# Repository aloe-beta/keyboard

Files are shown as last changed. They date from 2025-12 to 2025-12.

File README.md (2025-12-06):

# Keyboard

A low-profile split keyboard with 56 hotswappable, RGB backlit keys. Powered by an ESP32-S3.

This is the first project I'm trying to get a PCB manufactured for. I've polished the design up to a point I'm happy with, but there might be mistakes.

The directory structure should be self-explanatory. Currently, `firmare/` only contains a blink program. I'm still deciding whether I should try porting ZMK (ESP32-S3 requires some work) or writing my own firmware from scratch. The latter option would give me more freedom to experiment with the hardware (I have some unconventional ideas), so I'm leaning towards that.

The BOM does not contain anything for the housing or keycaps, as I intend to resin-print those myself.

**Schematic:**

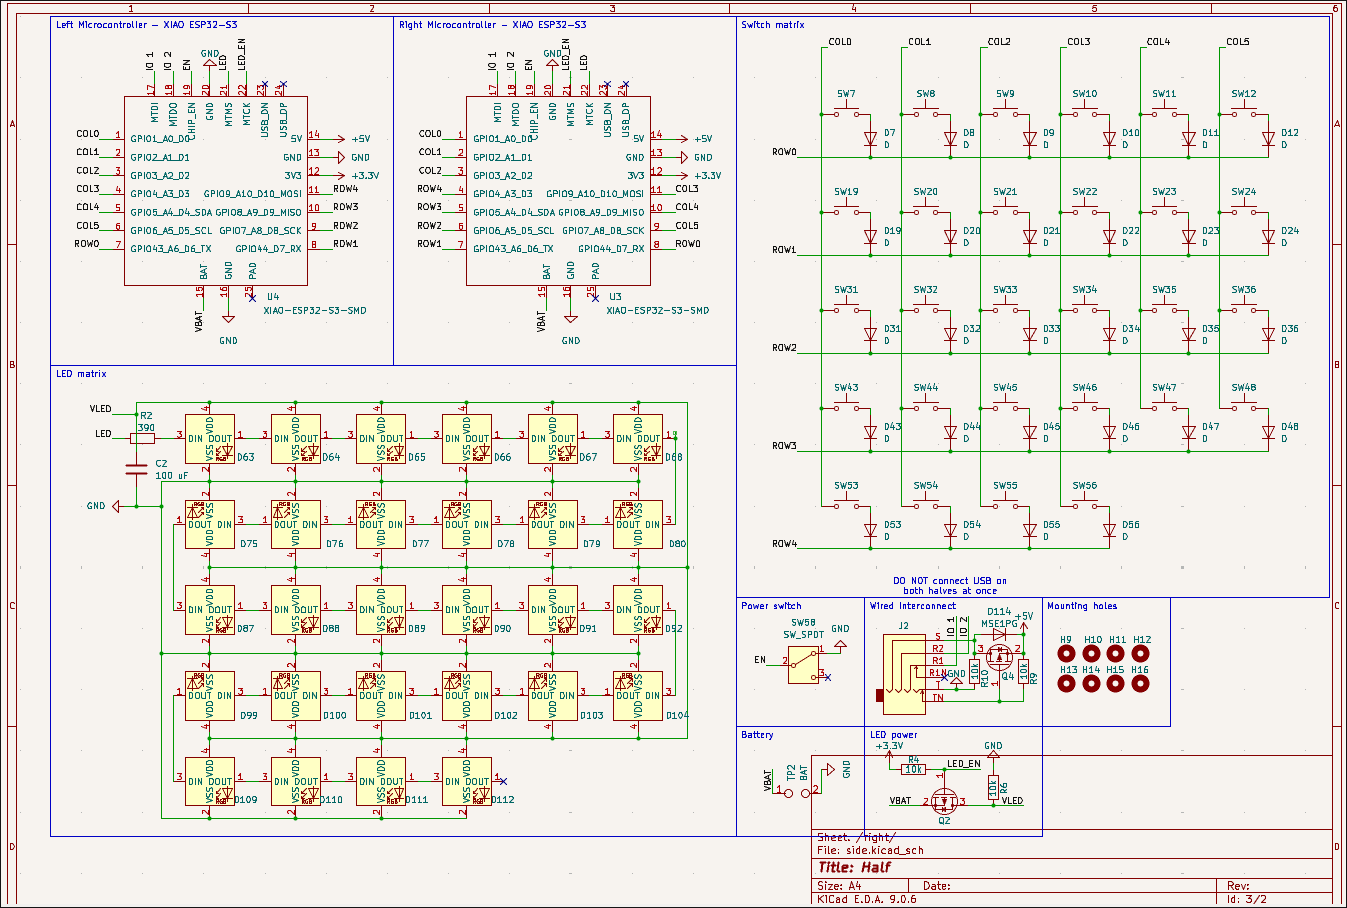
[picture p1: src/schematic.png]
Schematic


**PCB:**

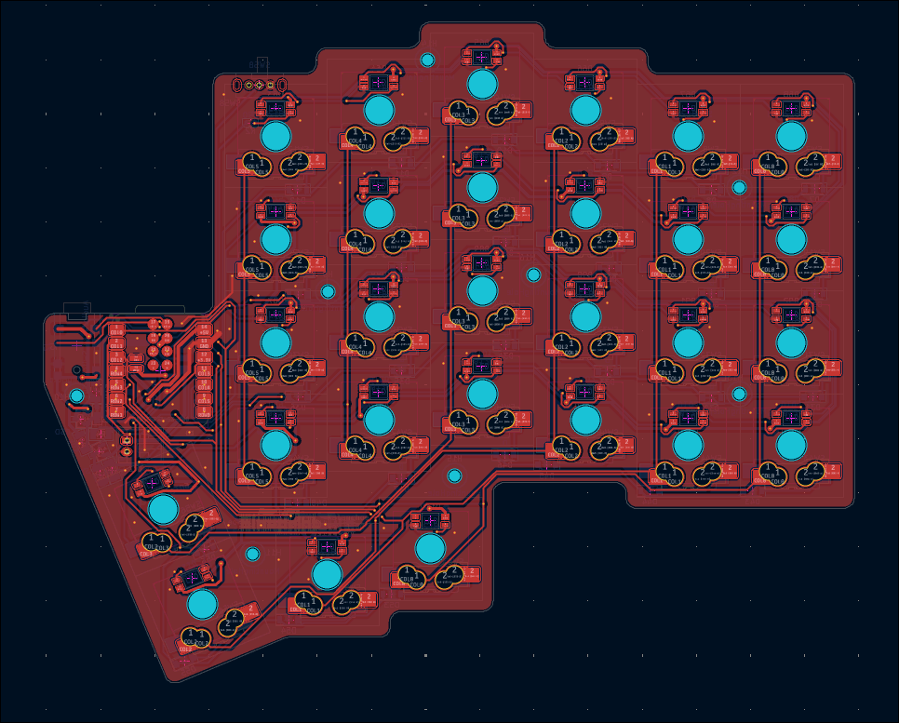
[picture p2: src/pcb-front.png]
Front

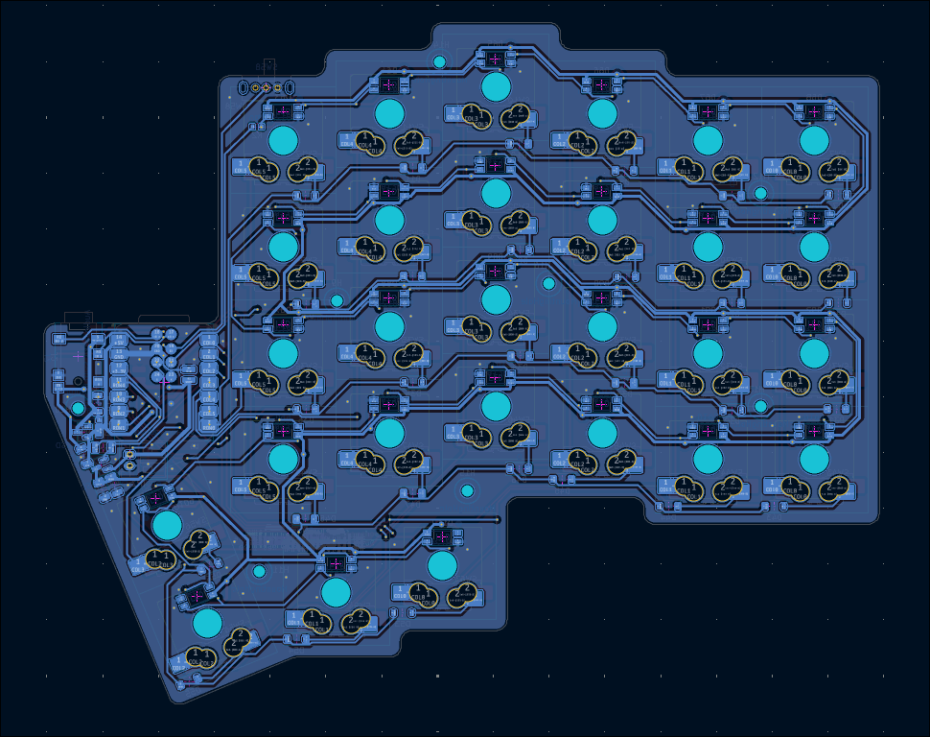
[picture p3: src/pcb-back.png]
Back


**Housing:**

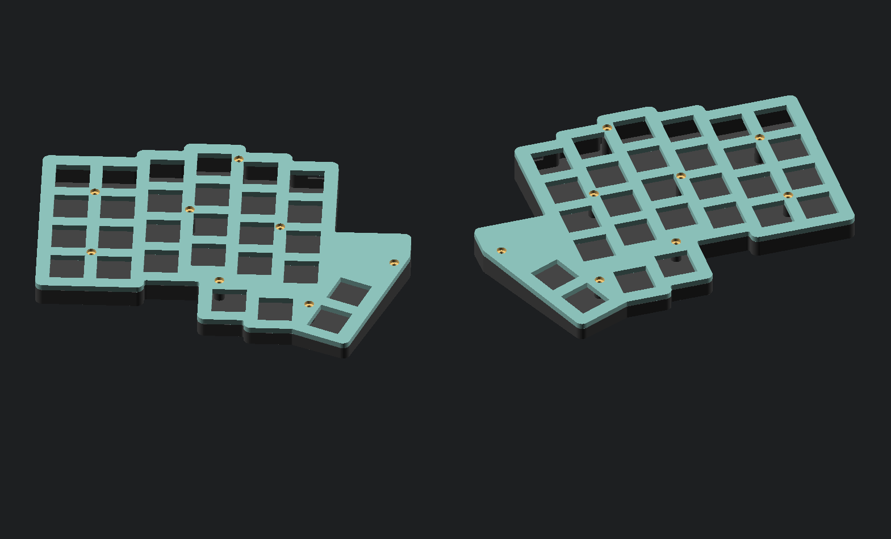
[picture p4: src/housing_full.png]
Housing

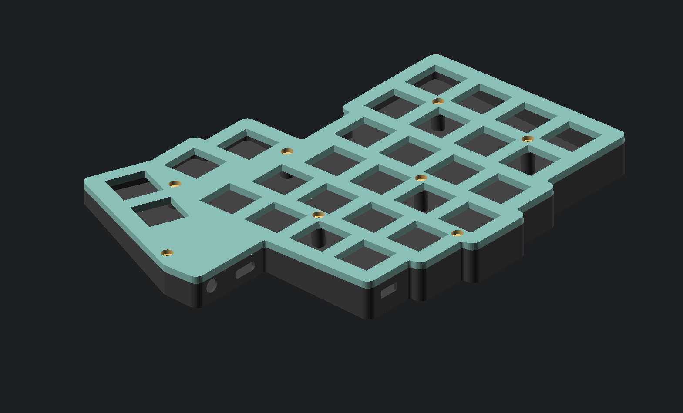
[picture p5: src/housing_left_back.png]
Housing (left side)

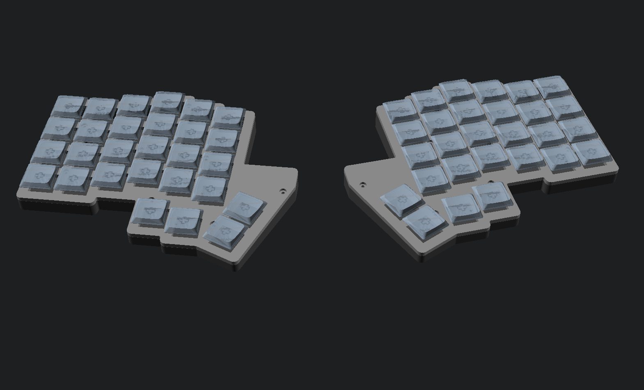
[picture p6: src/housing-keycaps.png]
Housing with keycaps


**Keycaps:**

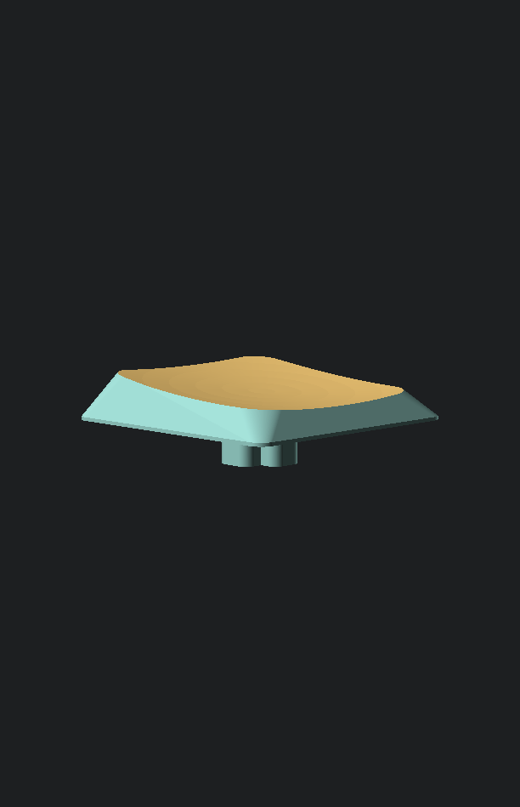
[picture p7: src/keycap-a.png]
Keycap (top angle)

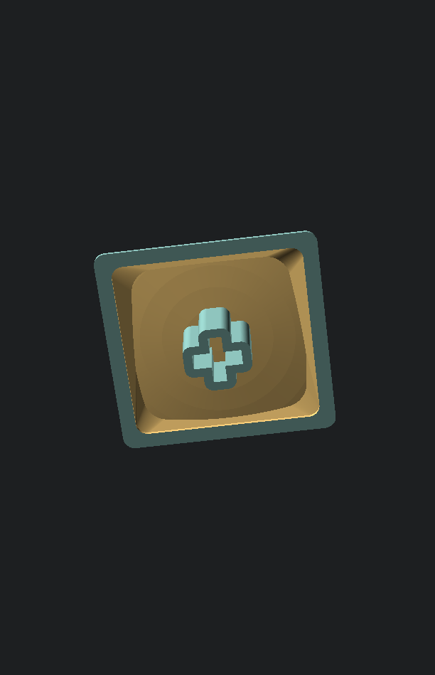
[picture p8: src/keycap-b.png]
Keycap (bottom angle)


**BOM:**

| Name | Description | Reference | Link | Quantity | Unit quantity | Unit price | Total price | Seller  |
| --- | --- | --- | --- | --- | --- | --- | --- | --- |
| 3.7V 1000mAh 502450 Lipo | Battery | N/A | https://www.amazon.com/dp/B07BTV3W87 | 2 | 2 | 7.4900 | 14.98 | Amazon  |
| CL31A107MQHNNWE | 100uF capacitor for the LEDs | C1-C2 | https://www.digikey.com/en/products/detail/samsung-electro-mechanics/CL31A107MQHNNWE/10479833 | 2 | 2 | 0.4000 | 0.80 | DigiKey |
| MSE1PG-M3 | Diodes for use in the wired interconnect | D113-D114 | https://www.digikey.com/en/products/detail/vishay-general-semiconductor-diodes-division/MSE1PG-M3-89A/2149917 | 2 | 2 | 0.1000 | 0.20 | DigiKey |
| 5149-LSH-3956D-005-G-19CT-ND | TRRS jacks for wired interconnect | J1-J2 | https://www.digikey.com/en/products/detail/linkplex/LSH-3956D-005-G-19/26798666 | 2 | 2 | 0.9900 | 1.98 | DigiKey |
| 4786-GSFC02501CT-ND | P-channel MOSFETs to toggle power to the LEDs and wired interconnect. | Q1-Q4 | https://www.digikey.com/en/products/detail/good-ark-semiconductor/GSFC02501/18648296 | 4 | 10 | 0.0390 | 0.39 | DigiKey |
| 311-390GRCT-ND | 390 ohm resistors for the first neopixel input lines | R1-R2 | https://www.digikey.com/en/products/detail/yageo/RC0603JR-07390RL/726777 | 2 | 10 | 0.0070 | 0.07 | DigiKey |
| 311-10.0KFRCT-ND | 10k ohm pull-up/pull-down resistors for MOSFET circuits | R3-R10 | https://www.digikey.com/en/products/detail/yageo/RC1206FR-0710KL/728483 | 8 | 10 | 0.0180 | 0.18 | DigiKey |
| 455-1719-ND | JST battery connector | TP1-TP2 | https://www.digikey.com/en/products/detail/jst-sales-america-inc/S2B-PH-K-S/926626 | 2 | 2 | 0.1000 | 0.20 | DigiKey |
| Seeed Studio XIAO ESP32-S3 | MCU | U3-U4 | https://www.digikey.com/en/products/detail/seeed-technology-co-ltd/113991114/19285530 | 2 | 2 | 7.4900 | 14.98 | DigiKey |
| GATERON Upgrade Hot-swap PCB 2.0 Socket | Hotswappable switch bracket | SW1-SW56  | https://www.gateron.com/products/gateron-hot-swap-pcb-socket?VariantsId=10170 | 56 | 1x70 | 7.0000 | 7.00 | Gateron |
| GATERON KS-33 Low Profile 2.0 Mechanical Switch | Low-profile mechanical switch | N/A | https://www.gateron.com/products/gateron-ks-33-low-profile-switch-set?VariantsId=11464 | 56 | 2x35 | 9.8000 | 19.60 | Gateron |
| PCB | The circuit board for the keyboard. | N/A | N/A | 1 | 1x5 | 21.8600 | 11.00 | JLC |
| Stencil | The stencil for soldering the board. | N/A | N/A | 1 | 1 | 7.0000 | 7.00 | JLC |
| 1N4148W | Diodes to prevent key ghosting | D1-D56 | https://www.lcsc.com/product-detail/C51953478.html | 56 | 56 | 0.0430 | 2.41 | LCSC |
| SK6812MINI-E | Addressable RGB LEDs for the backlight | D57-D112  | https://www.lcsc.com/product-detail/C5149201.html | 56 | 60 | 0.0683 | 4.10 | LCSC |
| SK12D07VG5 | Power switches | SW57-SW58 | https://www.lcsc.com/product-detail/C3020419.html | 2 | 20 | 0.0210 | 0.42 | LCSC |
| | | | | | | Tariffs | 1.50 | DigiKey |
| | | | | | | Shipping | 4.99 | DigiKey |
| | | | | | | Service Charge | 1.55 | Gateron |
| | | | | | | Shipping | 8.60 | Gateron |
| | | | | | | Shipping | 29.22 | JLC |
| | | | | | | Handling Fee | 3.00 | LCSC |
| | | | | | | Shipping | 8.42 | LCSC |
| | | | | | | Sales Tax | 7.84 | |
| | | | | | | Total | 150.43 | |

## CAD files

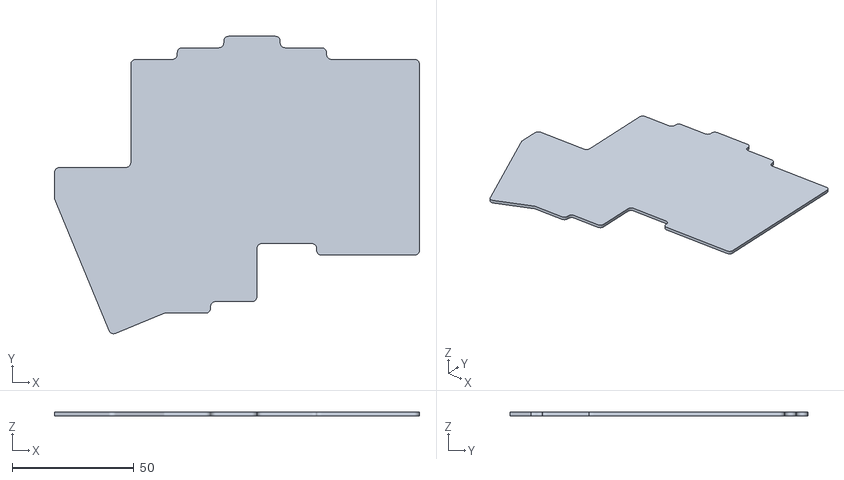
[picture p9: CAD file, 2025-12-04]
cad/right-blank.stl
149.8 x 122.1 x 1.51

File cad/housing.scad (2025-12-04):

include <BOSL2/std.scad>;
include <BOSL2/screws.scad>;

use <keycap.scad>;

Left = true;
Right = true;
Both = Left && Right;

Bottom = true;
Plate = true;
Keycaps = false;

$fn = 32;

/* [Hidden] */

z_offset = 6.3;
angle = 3.2;
h = z_offset * 2;

module outline(a = angle, half = -1) {
    projection() {
        rotate(a = a, v = [1, 0, 0]) 
        import(half == -1 ? "left-blank.stl" : "right-blank.stl", center = true);
    }
}

function holes(half) = half == -1 ? [[22.3625,10.872851],[-1.0375,-23.927149],[-53.75,-8.002149],[3.8125,52.972851],[36.05,-37.602149],[-53.85,29.997851],[69.55,-10.102149],[-15.6,13.397851]] : [[-68.688375,-8.102149],[-36.103996,-37.175354],[1.161625,-22.802149],[53.796004,-7.675354],[-3.788375,53.947851],[-21.703996,15.624646],[53.796004,30.424646],[15.711625,14.297851]];
function switches(half) = half == -1 ? [[12,-13.313328],[-26.1,5.736672],[31.05,39.074172],[21.525,-41.888328],[-7.05,29.549172],[31.05,0.974172],[-64.2,-18.075828],[-45.15,39.074172],[-45.15,-18.075828],[12,5.736672],[-26.1,24.786672],[31.05,20.024172],[12,43.836672],[-45.15,20.024172],[-7.05,-8.550828],[-26.1,-13.313328],[-7.05,48.599172],[-45.15,0.974172],[-26.1,43.836672],[12,24.786672],[-64.2,39.074172],[-7.05,10.499172],[-64.2,0.974172],[31.05,-18.075828],[2.475,-37.125828],[-64.2,20.024172]] : [[62.473125,20.360672],[5.323125,29.885672],[62.473125,1.310672],[-13.726875,25.123172],[62.473125,-17.739328],[5.323125,-8.214328],[43.423125,20.360672],[24.373125,44.173172],[-13.726875,44.173172],[-23.251875,-41.551828],[24.373125,25.123172],[-4.201875,-36.789328],[24.373125,-12.976828],[43.423125,39.410672],[5.323125,48.935672],[-13.726875,6.073172],[-32.776875,20.360672],[-32.776875,39.410672],[-32.776875,-17.739328],[43.423125,1.310672],[62.473125,39.410672],[-13.726875,-12.976828],[43.423125,-17.739328],[-32.776875,1.310672],[24.373125,6.073172],[5.323125,10.835672]];
function rotated_switches(half) = half == -1 ? [[51.973396,-29.39227],[44.683275,-46.992176]] : [[-52.537292,-28.928579],[-45.247172,-46.528485]];

module bottom(half = -1) {
    holes = holes(half);
    difference() {
        linear_extrude(height = h) 
        difference() {
            minkowski() {
                outline(half = half);
                circle(r = 1);
            }

            outline(half = half);
        }

        translate(v = [0, 0, h + 2.32])
        rotate(a = angle, v = [1, 0, 0]) 
        cube(size = [200, 200, h], center = true);

        translate(v = [0, 0, z_offset]) 
        rotate(a = angle, v = [1, 0, 0]) {
            // TRRS
            translate(v = [half * -69.074, 9.5, -0.8])
            rotate(a = 90, v = [1, 0, 0])  
            cylinder(h = 5, d = 5, center = true);

            // USB-C
            translate(v = [half * -53.672, 9.5, -2.15]) 
            rotate(a = 90, v = [1, 0, 0]) 
            linear_extrude(height = 5, center = true) 
            minkowski() {
                square(size = [6.5, .75], center = true);
                circle(r = 1.25);
            }

            // Switch
            translate(v = [half * -35.374, 52.5, -1.9])
            cube(size = [7, 5, 3], center = true);
        }
    }

    linear_extrude(height = 1) 
    minkowski() {
        outline(half = half);
        circle(r = 1);
    }

    difference() {
        rotate(a = angle, v = [1, 0, 0]) 
        for (hole = holes) {
            difference() {
                translate(v = [hole.x, hole.y, z_offset - h + .8])
                cylinder(r = 2.2, h = h);

                translate(v = [hole.x, hole.y, z_offset - 3]) 
                screw_hole("M2x0.4,8", thread = true);
            }
        }

        translate(v = [0, 0, -z_offset]) 
        cube(size = [200, 200, h], center = true);
    }
}

module plate(half = -1) {
    holes = holes(half);
    switches = switches(half);
    rotated_switches = rotated_switches(half);

    difference() {
        linear_extrude(height = 2.5) 
        difference() {
            minkowski() {
                outline(half = half);
                circle(r = 1);
            }

            for (switch = switches) {
                translate(v = [switch.x + 0.9, switch.y + 0.5])
                square(size = [14, 14], center = true);
            }

            for (switch = rotated_switches) {
                translate(v = switch) 
                rotate(a = half * 22.5, v = [0, 0, 1]) 
                square(size = [14, 14], center = true);
            }
        }

        translate(v = [0, 0, -1]) {
            linear_extrude(height = 2.5) {
                translate(v = [half*-68.5, 0])
                circle(r = 6);
            }

            linear_extrude(height = 3) {
                translate(v = [half*-60.5, -18.5])
                circle(r = 2);

                translate(v = [half*-35, 49.5]) 
                square(size = [16, 4], center = true);
            }
        }

        for (hole = holes) {
            translate(v = hole)
            cylinder(d = 2, h = 10, center = true);

            translate(v = [hole.x, hole.y, 2]) 
            cylinder(d = 4, h = 2, center = true);
        }
    }
}

module keycaps(half = -1) {
    switches = switches(half);
    rotated_switches = rotated_switches(half);

    for (switch = switches) {
        translate(v = [switch.x, switch.y, 9])
        keycap();
    }

    for (switch = rotated_switches) {
        translate(v = [switch.x, switch.y, 9])
        rotate(a = 22.5 * half, v = [0, 0, 1]) 
        keycap();
    }
}

for (half = Both ? [-1, 1] : Left ? -1 : Right ? 1 : []) {
    rotate(a = Both ? 10 : 0, v = [0, 0, half]) 
    translate(v = [Both ? 90 * half : 0, 0]) {
        if (Bottom) {
            color("#444")
            bottom(half);
        }

        if (Plate) {
            color(c = "#888") 
            translate(v = [0, 0, Bottom ? z_offset + 2.32 : 0]) 
            rotate(a = Bottom ? angle : 0, v = [1, 0, 0])
            plate(half);
        }

        if (Keycaps) {
            color(c = "#89aa") 
            translate(v = [0, 0, Bottom ? z_offset + 2.32 : 0]) 
            rotate(a = Bottom ? angle : 0, v = [1, 0, 0])
            keycaps(half);
        }
    }
}

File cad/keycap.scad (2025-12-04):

$fn = 128;

r1 = 1;
r2 = 2;
r3 = 75;

w1 = 18;
w2 = 15;

a = 5;

o = 1.1;
h = 2;

q1 = 0.5;
q2 = 1.25;

module cap(w1, w2, r1, r2, r3, h, q1, q2 = 0) {
    difference() {
        hull() {
            translate(v = [0, 0, q2 > 0 ? -.25 : 0]) 
            linear_extrude(height = q2 > 0 ? .5 : .25) 
            minkowski() {
                square(size = [w1 - (r1 + q2)*2, w1 - (r1 + q2)*2], center = true);
                circle(r = r1);
            }

            translate(v = [0, 0, h + q1 - q2]) 
            rotate(a = -a, v = [1, 0, 0]) 
            linear_extrude(height = .25) 
            minkowski() {
                square(size = [w2 - (r2 + q2)*2, w2 - (r2 + q2)*2], center = true);
                circle(r = r2);
            }
        }

        rotate(a = -a, v = [1, 0, 0]) 
        translate(v = [0, 0, r3 + h - q2]) 
        sphere(r = r3);
    }
}

module keycap(r1 = 1, r2 = 2, r3 = 75, w1 = 18, w2 = 15, a = 5, o = 1.1, h = 2, q1 = 0.5, q2 = 1.25) {
    translate(v = [0, 0, -4]) 
    linear_extrude(height = 4) 
    difference() {
        minkowski() {
            group() {
                square(size = [4, 1.28], center = true);
                square(size = [1.1, 4], center = true);
            }

            circle(r = .75);
        }

        square(size = [4, 1.28], center = true);
        square(size = [1.1, 4], center = true);
    }

    translate(v = [0, 0, -o]) 
    difference() {
        cap(w1, w2, r1, r2, r3, h, q1);
        cap(w1, w2, r1, r2, r3, h, q1, q2);
    }
}

keycap(r1, r2, r3, w1, w2, a, o, h, q1, q2);

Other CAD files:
cad/left-blank.stl

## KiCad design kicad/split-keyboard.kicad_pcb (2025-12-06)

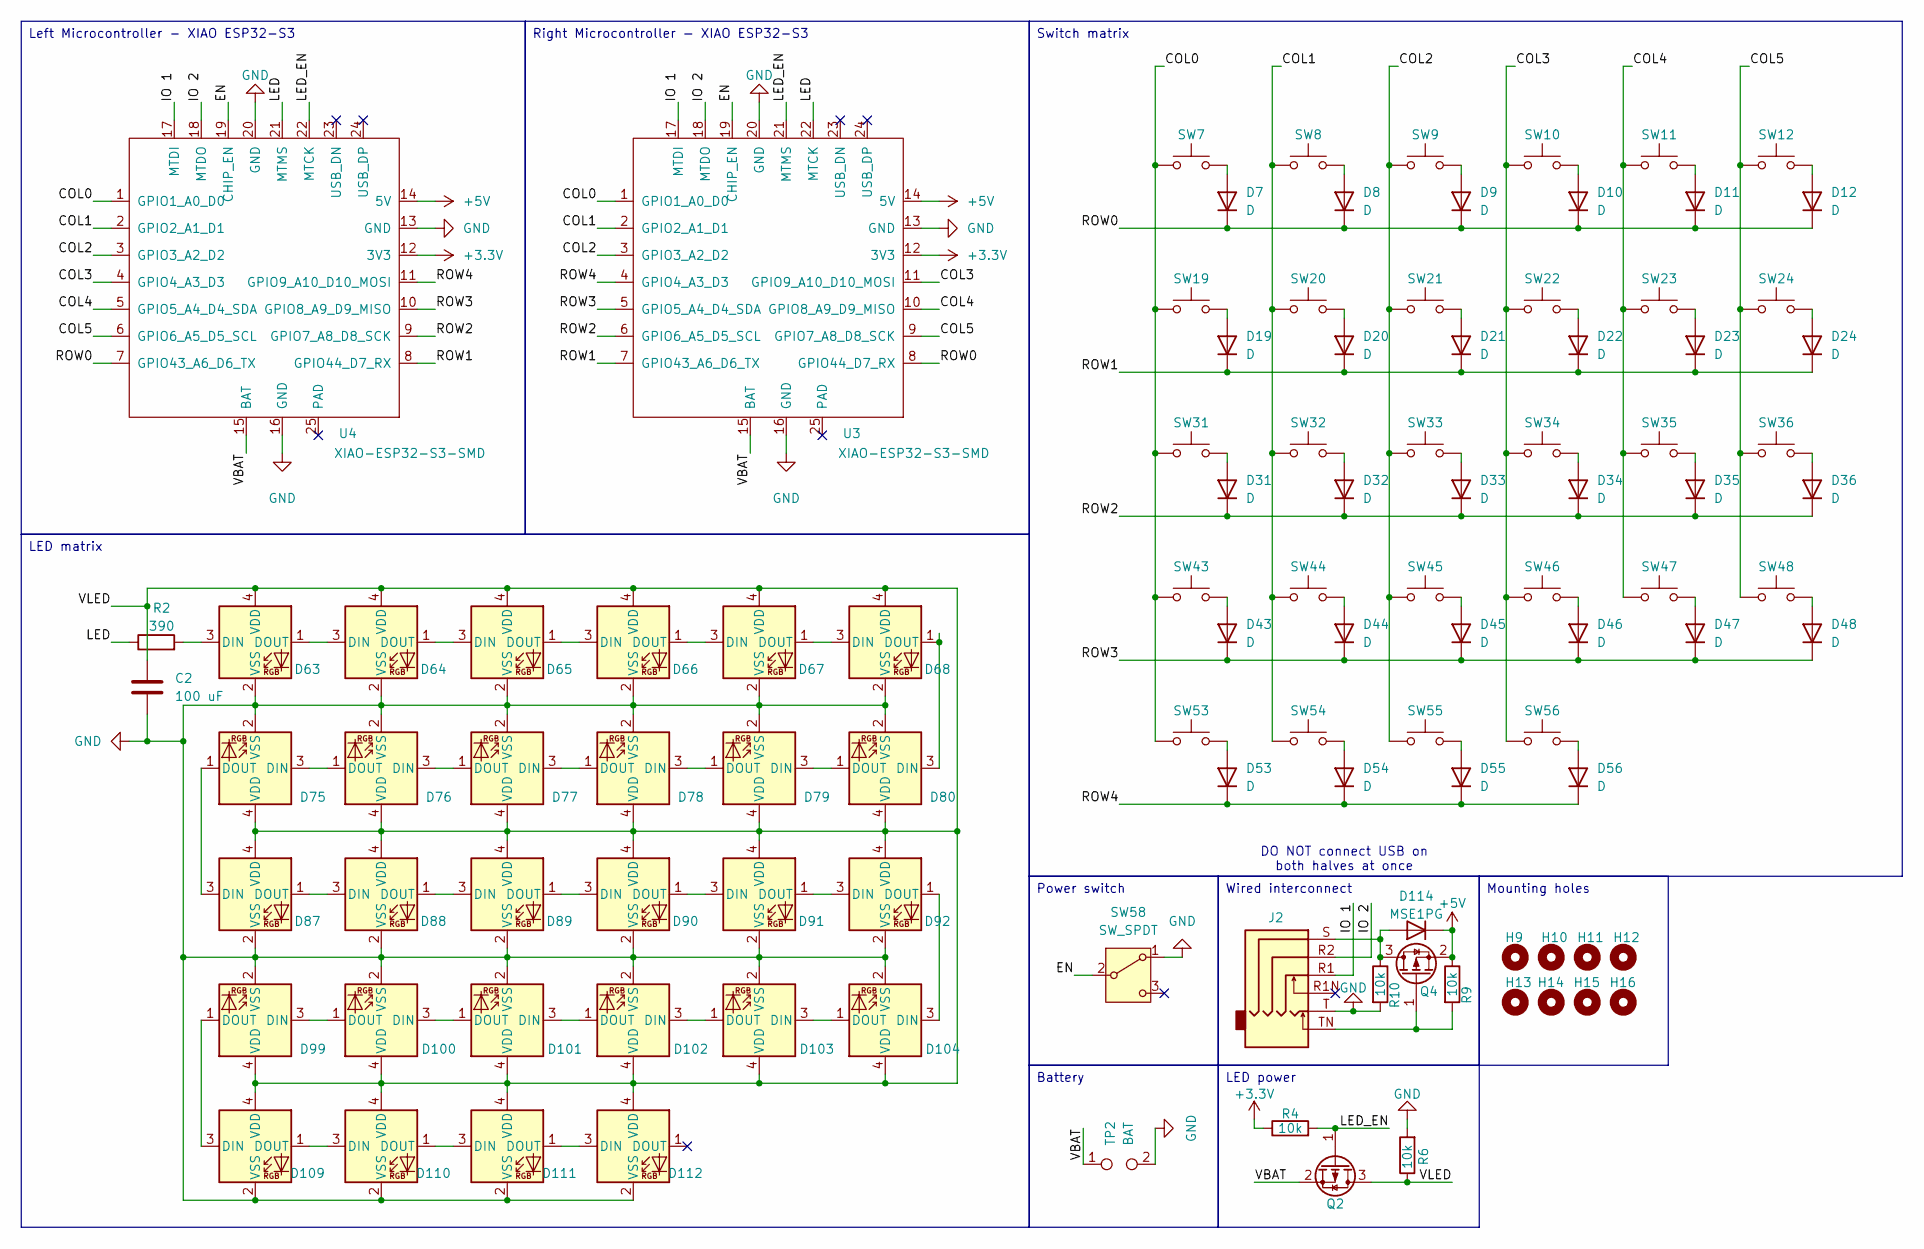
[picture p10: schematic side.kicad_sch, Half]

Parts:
C2: 100 uF; C_1206_3216Metric; LCSC C22399655
D7, D8, D9, D10, D11, D12, D19, D20, D21, D22, D23, D24, D31, D32, D33, D34, D35, D36, D43, D44, D45, D46, D47, D48, D53, D54, D55, D56: D; D_SOD-123; LCSC C169491
D63, D64, D65, D66, D67, D68, D75, D76, D77, D78, D79, D80, D87, D88, D89, D90, D91, D92, D99, D100, D101, D102, D103, D104, D109, D110, D111, D112: SK6812MINI; SK6812MINI-E_1-REV; LCSC C5149201
D114: MSE1PG; D_MicroSMP_AK; LCSC C94470
H9, H10, H11, H12, H13, H14, H15, H16: MountingHole; MountingHole_2.2mm_M2
J2: AudioJack4_SwitchTR1; LSH-3956D
Q2, Q4: Q_PMOS_GSD; SOT-23; LCSC C2589
R2: 390; R_0603_1608Metric; LCSC C190196
R4, R6, R9, R10: 10k; R_1206_3216Metric; LCSC C702844
SW7, SW8, SW9, SW10, SW11, SW12, SW19, SW20, SW21, SW22, SW23, SW24, SW31, SW32, SW33, SW34, SW35, SW36, SW43, SW44, SW45, SW46, SW47, SW48, SW53, SW54, SW55, SW56: SW_Push; SW_KS33_HS_KS-2P02B01-02_HS_1u; LCSC C9900205432
SW58: SW_SPDT; SK12D07VG5; LCSC C2896621
TP2: BAT; JST_PH_S2B-PH-K_1x02_P2.00mm_Horizontal; LCSC C173752
U3, U4: XIAO-ESP32-S3-SMD; XIAO-ESP32S3-SMD; LCSC C9900124959

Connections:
+3.3V: R4.1, U3.12 (3V3), U4.12 (3V3)
+5V: D114.1 (K), Q4.2 (S), R9.1, U3.14 (5V), U4.14 (5V)
/right/COL0: SW7.1, SW19.1, SW31.1, SW43.1, SW53.1, U3.1 (GPIO1_A0_D0), U4.1 (GPIO1_A0_D0)
/right/COL1: SW8.1, SW20.1, SW32.1, SW44.1, SW54.1, U3.2 (GPIO2_A1_D1), U4.2 (GPIO2_A1_D1)
/right/COL2: SW9.1, SW21.1, SW33.1, SW45.1, SW55.1, U3.3 (GPIO3_A2_D2), U4.3 (GPIO3_A2_D2)
/right/COL3: SW10.1, SW22.1, SW34.1, SW46.1, SW56.1, U3.11 (GPIO9_A10_D10_MOSI), U4.4 (GPIO4_A3_D3)
/right/COL4: SW11.1, SW23.1, SW35.1, SW47.1, U3.10 (GPIO8_A9_D9_MISO), U4.5 (GPIO5_A4_D4_SDA)
/right/COL5: SW12.1, SW24.1, SW36.1, SW48.1, U3.9 (GPIO7_A8_D8_SCK), U4.6 (GPIO6_A5_D5_SCL)
/right/EN: SW58.2 (B), U3.19 (CHIP_EN), U4.19 (CHIP_EN)
/right/IO 1: J2.R1, U3.17 (MTDI), U4.17 (MTDI)
/right/IO 2: J2.R2, U3.18 (MTDO), U4.18 (MTDO)
/right/LED: R2.1, U3.22 (MTCK), U4.21 (MTMS)
/right/LED_EN: Q2.1 (G), R4.2, U3.21 (MTMS), U4.22 (MTCK)
/right/ROW0: D7.1 (K), D8.1 (K), D9.1 (K), D10.1 (K), D11.1 (K), D12.1 (K), U3.8 (GPIO44_D7_RX), U4.7 (GPIO43_A6_D6_TX)
/right/ROW1: D19.1 (K), D20.1 (K), D21.1 (K), D22.1 (K), D23.1 (K), D24.1 (K), U3.7 (GPIO43_A6_D6_TX), U4.8 (GPIO44_D7_RX)
/right/ROW2: D31.1 (K), D32.1 (K), D33.1 (K), D34.1 (K), D35.1 (K), D36.1 (K), U3.6 (GPIO6_A5_D5_SCL), U4.9 (GPIO7_A8_D8_SCK)
/right/ROW3: D43.1 (K), D44.1 (K), D45.1 (K), D46.1 (K), D47.1 (K), D48.1 (K), U3.5 (GPIO5_A4_D4_SDA), U4.10 (GPIO8_A9_D9_MISO)
/right/ROW4: D53.1 (K), D54.1 (K), D55.1 (K), D56.1 (K), U3.4 (GPIO4_A3_D3), U4.11 (GPIO9_A10_D10_MOSI)
/right/VBAT: Q2.2 (S), TP2.1, U3.15 (BAT), U4.15 (BAT)
/right/VLED: C2.1, D63.4 (VDD), D64.4 (VDD), D65.4 (VDD), D66.4 (VDD), D67.4 (VDD), D68.4 (VDD), D75.4 (VDD), D76.4 (VDD), D77.4 (VDD), D78.4 (VDD), D79.4 (VDD), D80.4 (VDD), D87.4 (VDD), D88.4 (VDD), D89.4 (VDD), D90.4 (VDD), D91.4 (VDD), D92.4 (VDD), D99.4 (VDD), D100.4 (VDD), D101.4 (VDD), D102.4 (VDD), D103.4 (VDD), D104.4 (VDD), D109.4 (VDD), D110.4 (VDD), D111.4 (VDD), D112.4 (VDD), Q2.3 (D), R6.1
GND: C2.2, D63.2 (VSS), D64.2 (VSS), D65.2 (VSS), D66.2 (VSS), D67.2 (VSS), D68.2 (VSS), D75.2 (VSS), D76.2 (VSS), D77.2 (VSS), D78.2 (VSS), D79.2 (VSS), D80.2 (VSS), D87.2 (VSS), D88.2 (VSS), D89.2 (VSS), D90.2 (VSS), D91.2 (VSS), D92.2 (VSS), D99.2 (VSS), D100.2 (VSS), D101.2 (VSS), D102.2 (VSS), D103.2 (VSS), D104.2 (VSS), D109.2 (VSS), D110.2 (VSS), D111.2 (VSS), D112.2 (VSS), J2.T, R6.2, R10.2, SW58.1 (A), TP2.2, U3.13 (GND), U3.16 (GND), U3.20 (GND), U4.13 (GND), U4.16 (GND), U4.20 (GND)
unnamed: D7.2 (A), SW7.2
unnamed: D8.2 (A), SW8.2
unnamed: D9.2 (A), SW9.2
unnamed: D10.2 (A), SW10.2
unnamed: D11.2 (A), SW11.2
unnamed: D12.2 (A), SW12.2
unnamed: D19.2 (A), SW19.2
unnamed: D20.2 (A), SW20.2
unnamed: D21.2 (A), SW21.2
unnamed: D22.2 (A), SW22.2
unnamed: D23.2 (A), SW23.2
unnamed: D24.2 (A), SW24.2
unnamed: D31.2 (A), SW31.2
unnamed: D32.2 (A), SW32.2
unnamed: D33.2 (A), SW33.2
unnamed: D34.2 (A), SW34.2
unnamed: D35.2 (A), SW35.2
unnamed: D36.2 (A), SW36.2
unnamed: D43.2 (A), SW43.2
unnamed: D44.2 (A), SW44.2
unnamed: D45.2 (A), SW45.2
unnamed: D46.2 (A), SW46.2
unnamed: D47.2 (A), SW47.2
unnamed: D48.2 (A), SW48.2
unnamed: D53.2 (A), SW53.2
unnamed: D54.2 (A), SW54.2
unnamed: D55.2 (A), SW55.2
unnamed: D56.2 (A), SW56.2
unnamed: D63.3 (DIN), R2.2
unnamed: D63.1 (DOUT), D64.3 (DIN)
unnamed: D64.1 (DOUT), D65.3 (DIN)
unnamed: D65.1 (DOUT), D66.3 (DIN)
unnamed: D66.1 (DOUT), D67.3 (DIN)
unnamed: D67.1 (DOUT), D68.3 (DIN)
unnamed: D68.1 (DOUT), D80.3 (DIN)
unnamed: D75.3 (DIN), D76.1 (DOUT)
unnamed: D75.1 (DOUT), D87.3 (DIN)
unnamed: D76.3 (DIN), D77.1 (DOUT)
unnamed: D77.3 (DIN), D78.1 (DOUT)
unnamed: D78.3 (DIN), D79.1 (DOUT)
unnamed: D79.3 (DIN), D80.1 (DOUT)
unnamed: D87.1 (DOUT), D88.3 (DIN)
unnamed: D88.1 (DOUT), D89.3 (DIN)
unnamed: D89.1 (DOUT), D90.3 (DIN)
unnamed: D90.1 (DOUT), D91.3 (DIN)
unnamed: D91.1 (DOUT), D92.3 (DIN)
unnamed: D100.3 (DIN), D101.1 (DOUT)
unnamed: D99.3 (DIN), D100.1 (DOUT)
unnamed: D101.3 (DIN), D102.1 (DOUT)
unnamed: D102.3 (DIN), D103.1 (DOUT)
unnamed: D103.3 (DIN), D104.1 (DOUT)
unnamed: D92.1 (DOUT), D104.3 (DIN)
unnamed: D99.1 (DOUT), D109.3 (DIN)
unnamed: D109.1 (DOUT), D110.3 (DIN)
unnamed: D110.1 (DOUT), D111.3 (DIN)
unnamed: D111.1 (DOUT), D112.3 (DIN)
unnamed: D114.2 (A), J2.S, Q4.3 (D), R10.1
unnamed: J2.TN, Q4.1 (G), R9.2

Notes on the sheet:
DO NOT connect USB on both halves at once
Switch matrix
Wired interconnect
Battery
Right Microcontroller - XIAO ESP32-S3
Left Microcontroller - XIAO ESP32-S3
LED power
Power switch
LED matrix
Mounting holes

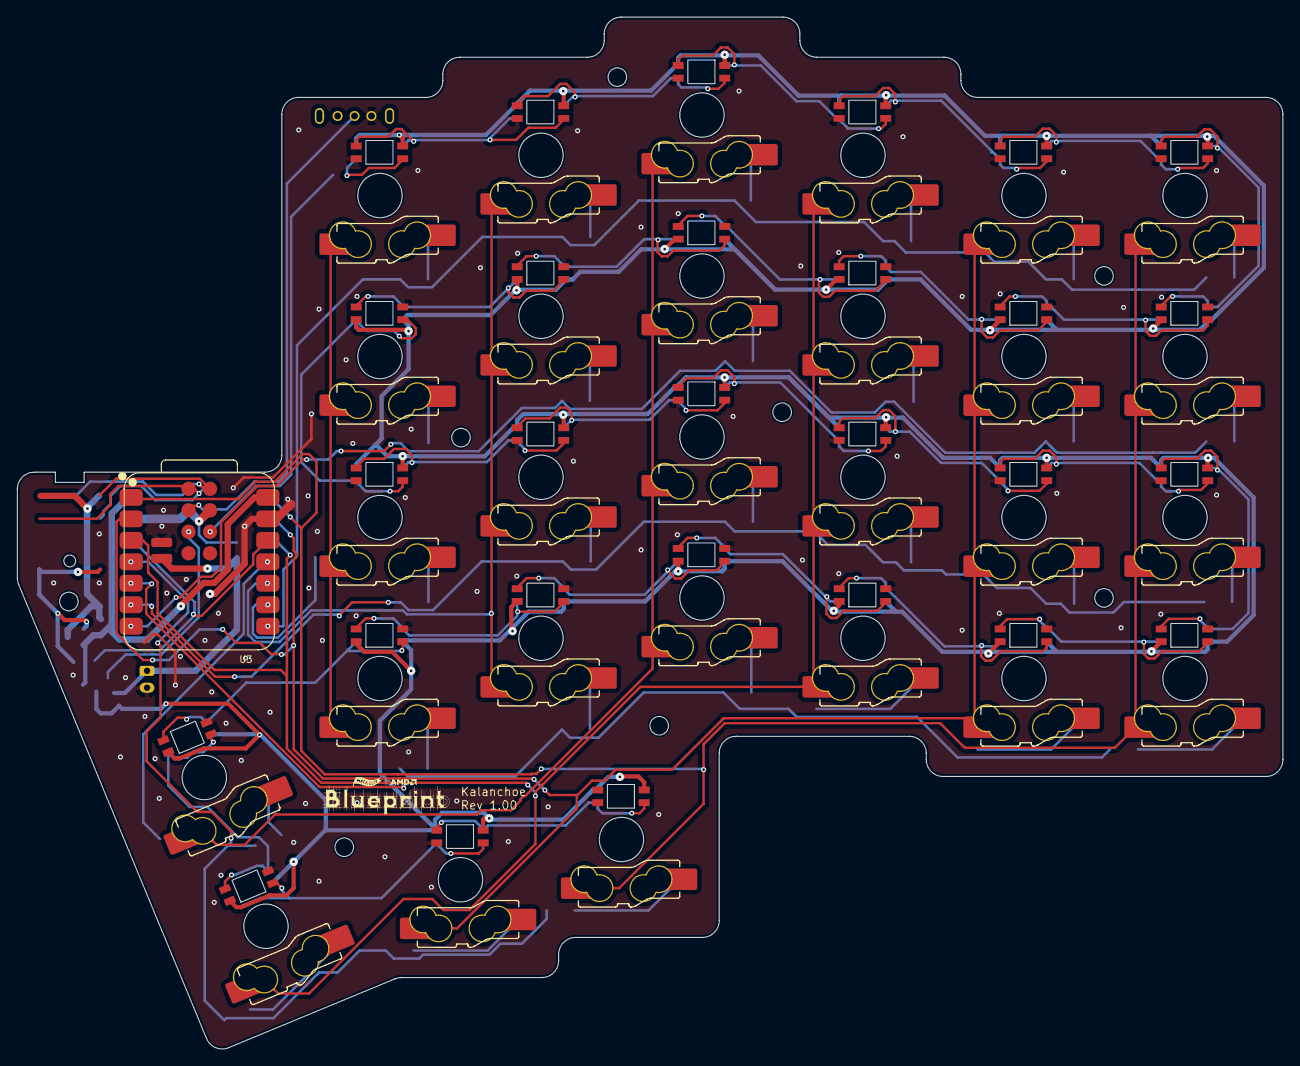
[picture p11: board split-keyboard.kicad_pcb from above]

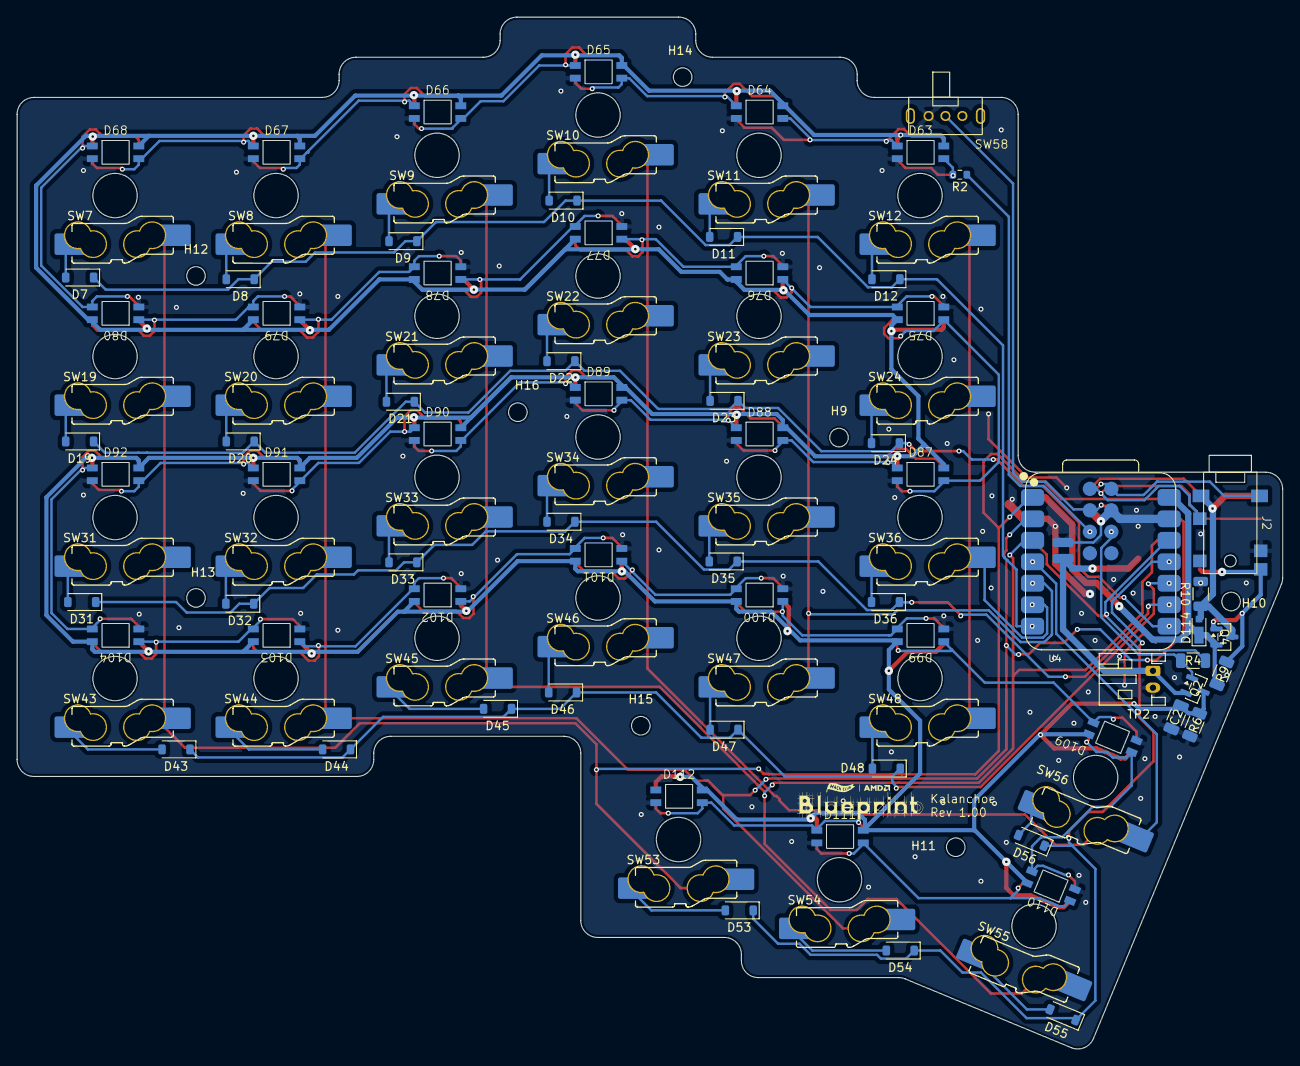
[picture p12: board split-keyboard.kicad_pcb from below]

Board: 2 copper layers, 149.8 x 122.1 mm, 106 parts (105 on the bottom side), 79 nets.

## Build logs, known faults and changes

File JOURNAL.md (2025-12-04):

<!--
  ===================    !!READ THIS NOTICE!!   ====================
  DO NOT edit this file manually. Your changes WILL BE OVERWRITTEN!
  This journal is auto generated and updated by Hack Club Blueprint.
  To edit this file, please edit your journal entries on Blueprint.
  ==================================================================
-->

## 10/22/2025 - Created schematic  

I'm following the split keyboard guide as a first project on here. I spend most of my time reading through documentation to find a microcontroller that would work with the split layout I planned, and re-learning how to use KiCAD (it's been a while). I skipped adding a battery sensor pin, as the microcontroller I selected appears to have that built-in. I added a TRRS jack to share power when charging and to transmit data over a wired connection between the halves.
  

## 10/23/2025 - Routed PCBs  

I routed both PCBs, connected to each other through mousebites. I ended up adding more mounting holes and changing the battery test pads into a single double testpad on the schematic, to add a JST connector for the battery on each PCB (footprint-symbol linking).


  

## 10/24/2025 - Rerouted PCB  

Apparently I put all the switch brackets on the wrong side of the board. I deleted all the traces, moved the brackets to the back, and rerouted everything. I figured this time I might as well make the traces follow a more consistent layout, so I cleaned things up a bit with those as well.





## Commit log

2025-12-04 Prepared for design review
    [bom.csv, housing.scad, keycap.scad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]
2025-12-04 Updated BOM and fixed README issue
    [bom.csv]
2025-12-04 Added BOM to README
2025-12-06 Rerouted PCB
    [bom.csv, side.kicad_sch, split-keyboard.kicad_pcb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]
